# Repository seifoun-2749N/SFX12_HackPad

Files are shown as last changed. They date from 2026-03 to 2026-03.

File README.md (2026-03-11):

# SFX12 HackPad

<div align="center">

Affiche HackPad(1)

**A custom 12-key macropad with rotary encoder and SK6812 RGB LEDs.**

</div>

---

## Overview :

A custom macropad made with 12 mechanical switches and a rotay encoder with creative and chic design . It's also an open source device that you can build it yourself and costumize it like you want. 

---

## Features :

- 12 mechanical switches
- Rotary encoder
- 5 * SK6812 RGB LEDs 
- Tap dance on every key
- 12 app launchers
- Dedicated shortcut row

---

## Hardware :

* Seeeduino XIAO (1) SAMD21G18
* mechanical switches (12) MX-compatible
* EC11 (1) Rotary encoder with push button
* SK6812 (5) addressable RGB LEDs
* 1N4148 (12) signal diodes

---

## PCB and Shematics :

### PCB Front
PCB

### PCB Back
PCB Back

### Schematic


---

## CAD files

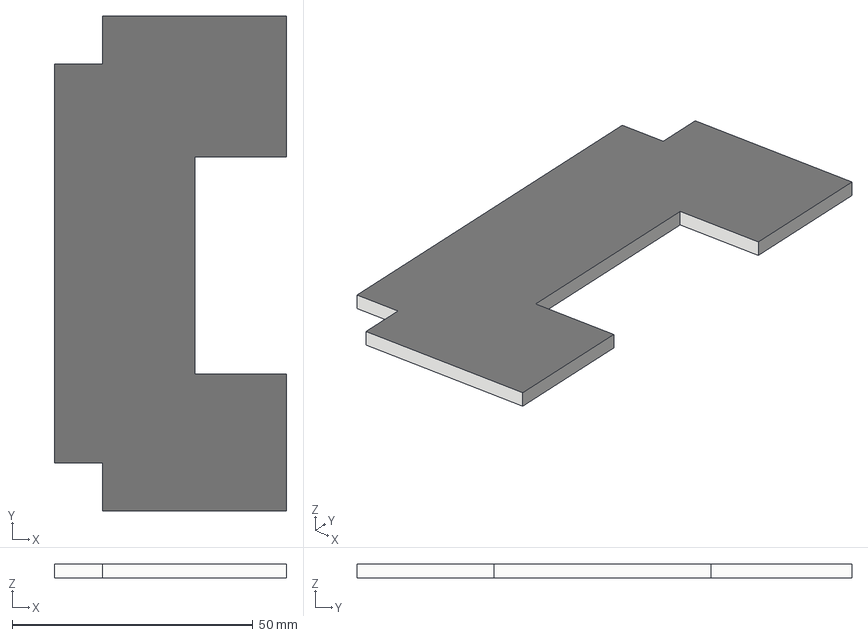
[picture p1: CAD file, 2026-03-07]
Cad/Transparent Layer.step
48.3 x 102.9 x 3.00 mm

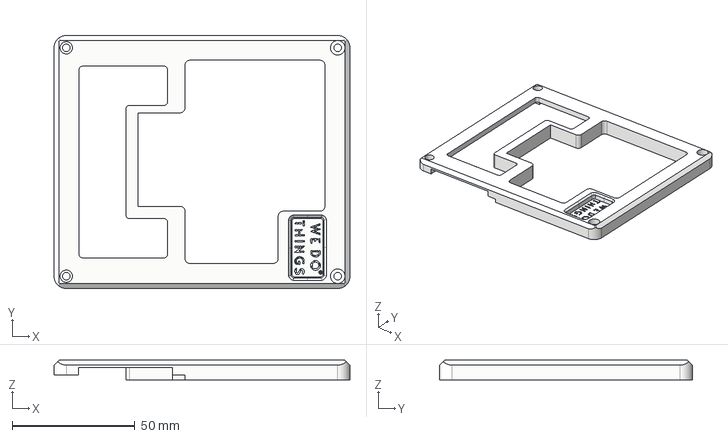
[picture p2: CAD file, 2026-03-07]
Cad/Top.step
120.4 x 102.9 x 8.00 mm

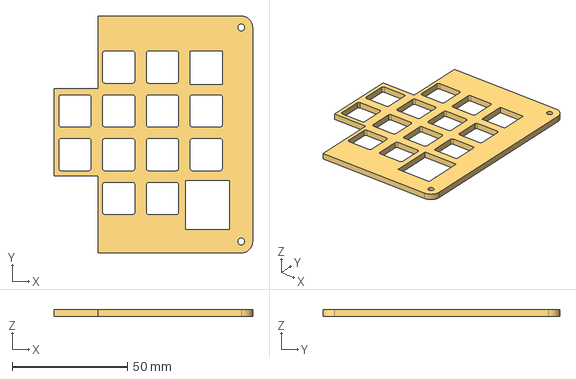
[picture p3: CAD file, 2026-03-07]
Cad/Frame.step
86.2 x 102.9 x 3.00 mm

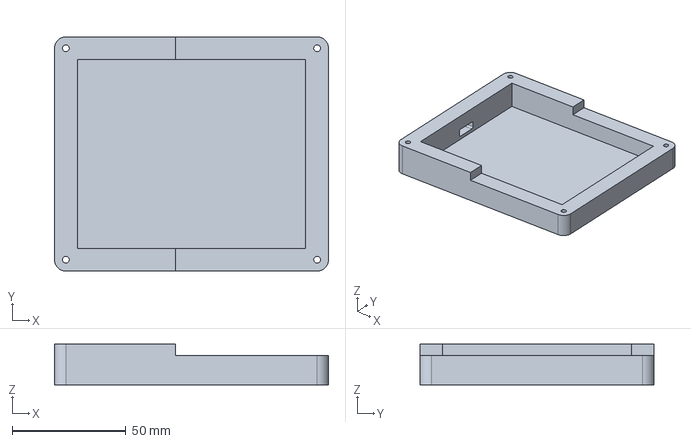
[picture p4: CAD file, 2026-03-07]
Cad/Base.step
120.4 x 102.9 x 18.0 mm

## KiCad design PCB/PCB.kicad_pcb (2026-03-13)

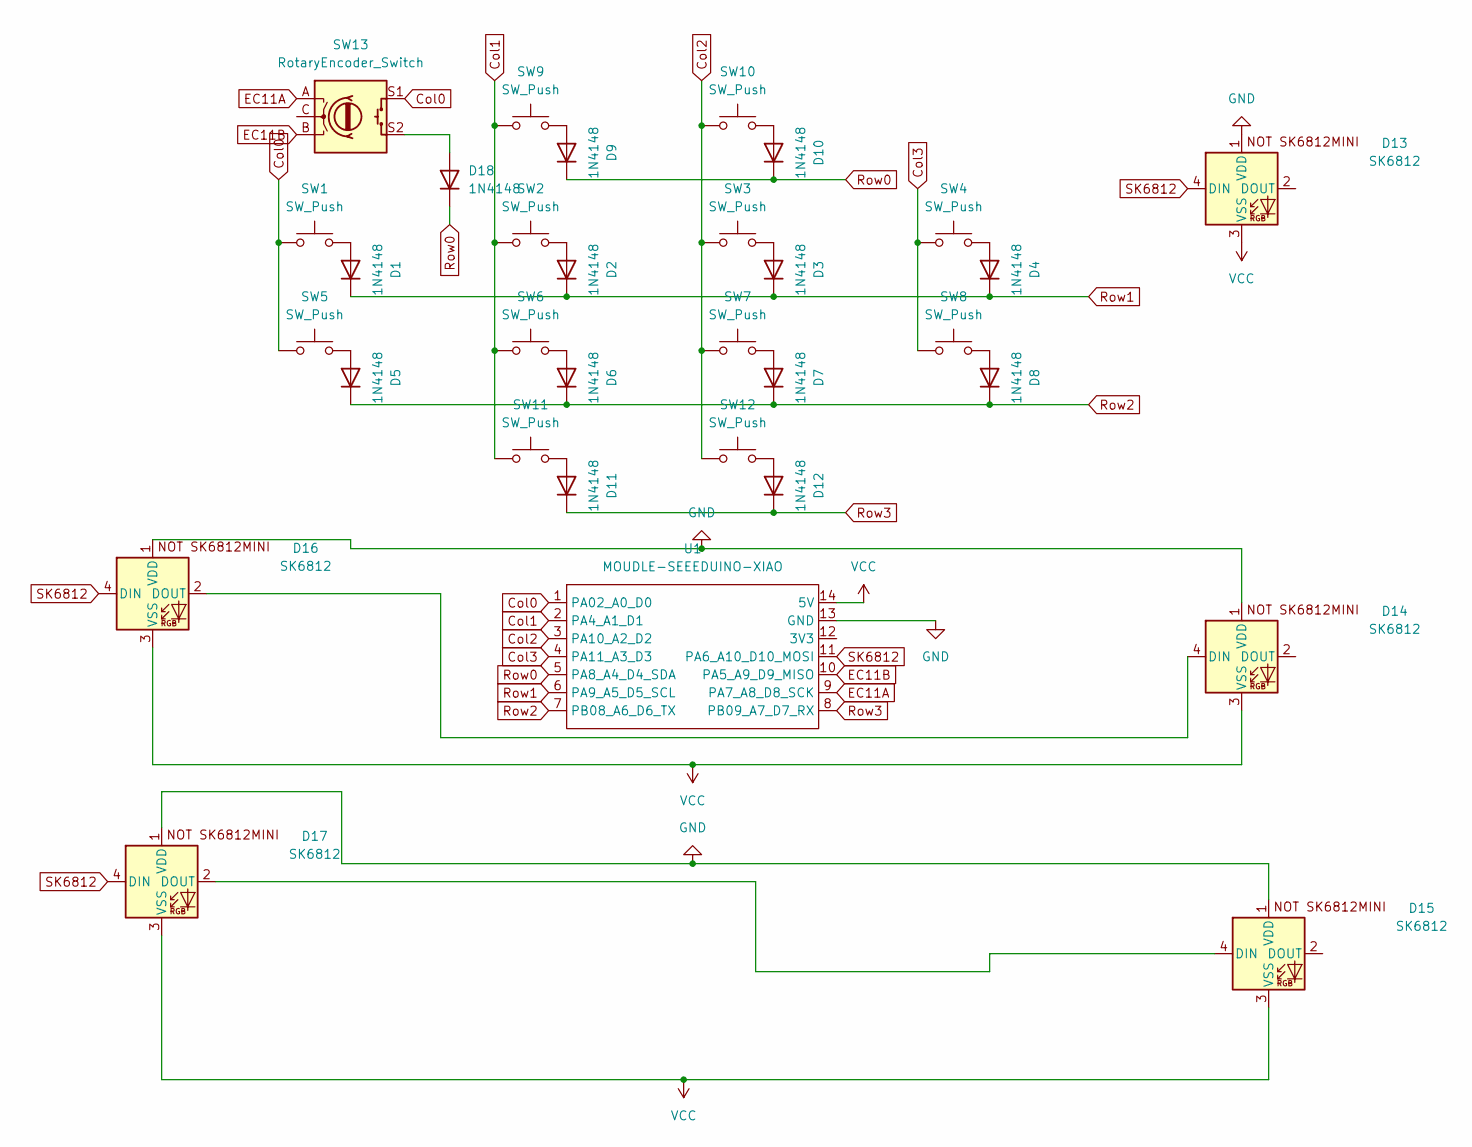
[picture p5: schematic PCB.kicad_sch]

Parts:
D1, D2, D3, D4, D5, D6, D7, D8, D9, D10, D11, D12, D18: 1N4148; D_DO-35_SOD27_P7.62mm_Horizontal
D13, D14, D15, D16, D17: SK6812; SK6812MINI-E - 3.2x2.8x1.78mm
SW1, SW2, SW3, SW4, SW5, SW6, SW7, SW8, SW9, SW10, SW11, SW12: SW_Push; SW_Cherry_MX_1.00u_PCB
SW13: RotaryEncoder_Switch; RotaryEncoder_Alps_EC11E-Switch_Vertical_H20mm
U1: MOUDLE-SEEEDUINO-XIAO; XIAO-Generic-Hybrid-14P-2.54-21X17.8MM

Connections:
Col0: SW1.1, SW5.1, SW13.S1, U1.1 (PA02_A0_D0)
Col1: SW2.1, SW6.1, SW9.1, SW11.1, U1.2 (PA4_A1_D1)
Col2: SW3.1, SW7.1, SW10.1, SW12.1, U1.3 (PA10_A2_D2)
Col3: SW4.1, SW8.1, U1.4 (PA11_A3_D3)
EC11A: SW13.A, U1.9 (PA7_A8_D8_SCK)
EC11B: SW13.B, U1.10 (PA5_A9_D9_MISO)
GND: D13.1 (VDD), D14.1 (VDD), D15.1 (VDD), D16.1 (VDD), D17.1 (VDD), U1.13 (GND)
unnamed: D1.2 (A), SW1.2
unnamed: D2.2 (A), SW2.2
unnamed: D3.2 (A), SW3.2
unnamed: D4.2 (A), SW4.2
unnamed: D5.2 (A), SW5.2
unnamed: D6.2 (A), SW6.2
unnamed: D7.2 (A), SW7.2
unnamed: D8.2 (A), SW8.2
unnamed: D9.2 (A), SW9.2
unnamed: D10.2 (A), SW10.2
unnamed: D11.2 (A), SW11.2
unnamed: D12.2 (A), SW12.2
unnamed: D14.4 (DIN), D16.2 (DOUT)
unnamed: D15.4 (DIN), D17.2 (DOUT)
unnamed: D18.2 (A), SW13.S2
Row0: D9.1 (K), D10.1 (K), D18.1 (K), U1.5 (PA8_A4_D4_SDA)
Row1: D1.1 (K), D2.1 (K), D3.1 (K), D4.1 (K), U1.6 (PA9_A5_D5_SCL)
Row2: D5.1 (K), D6.1 (K), D7.1 (K), D8.1 (K), U1.7 (PB08_A6_D6_TX)
Row3: D11.1 (K), D12.1 (K), U1.8 (PB09_A7_D7_RX)
SK6812: D13.4 (DIN), D16.4 (DIN), D17.4 (DIN), U1.11 (PA6_A10_D10_MOSI)
VCC: D13.3 (VSS), D14.3 (VSS), D15.3 (VSS), D16.3 (VSS), D17.3 (VSS), U1.14 (5V)

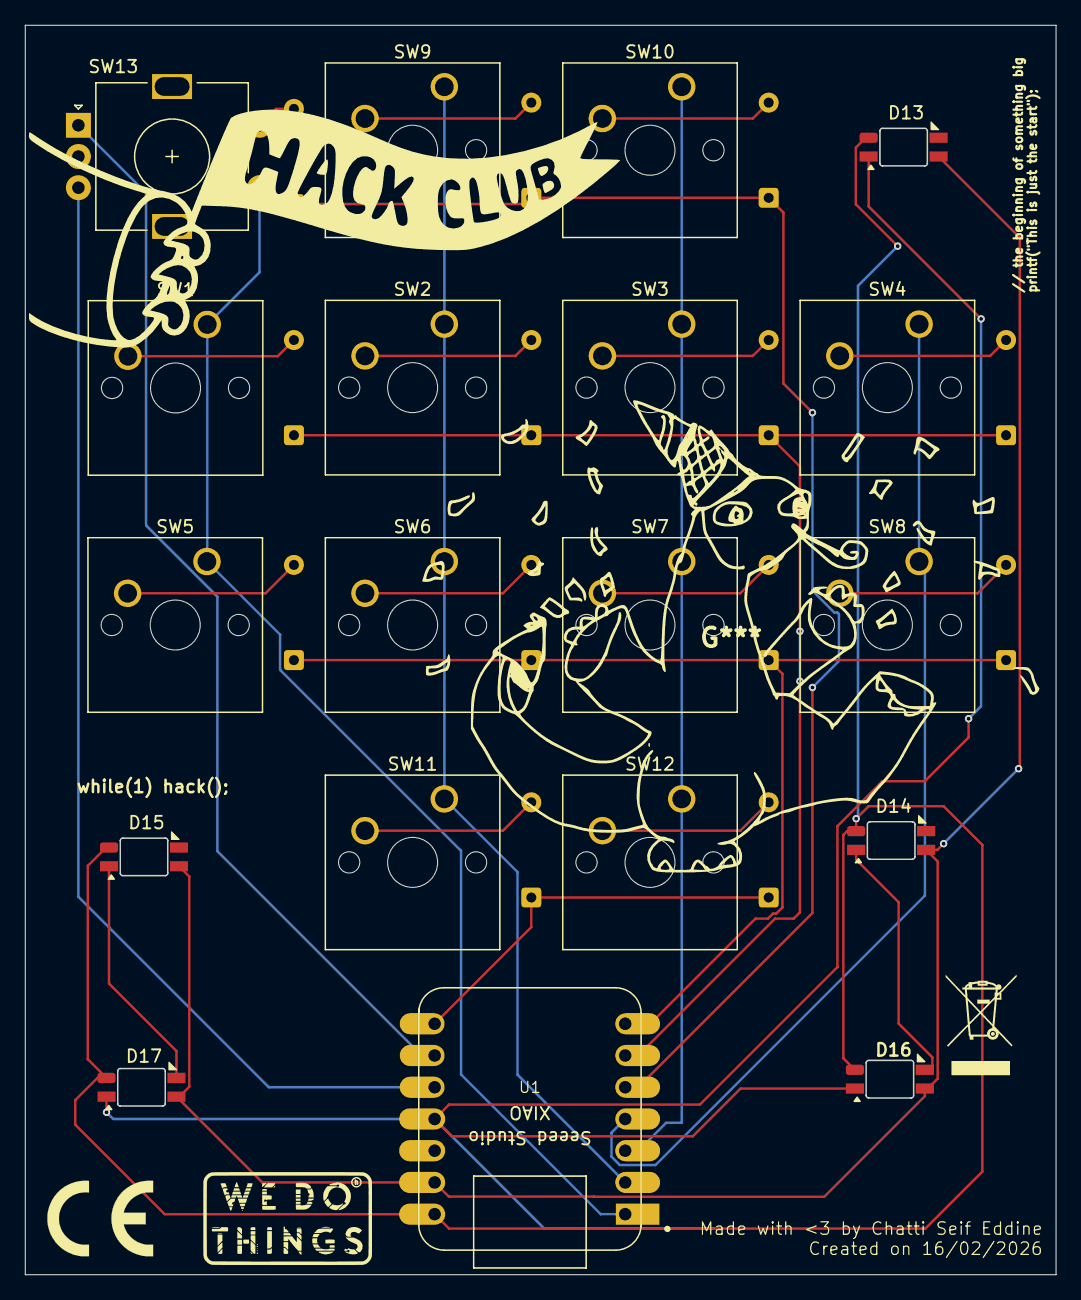
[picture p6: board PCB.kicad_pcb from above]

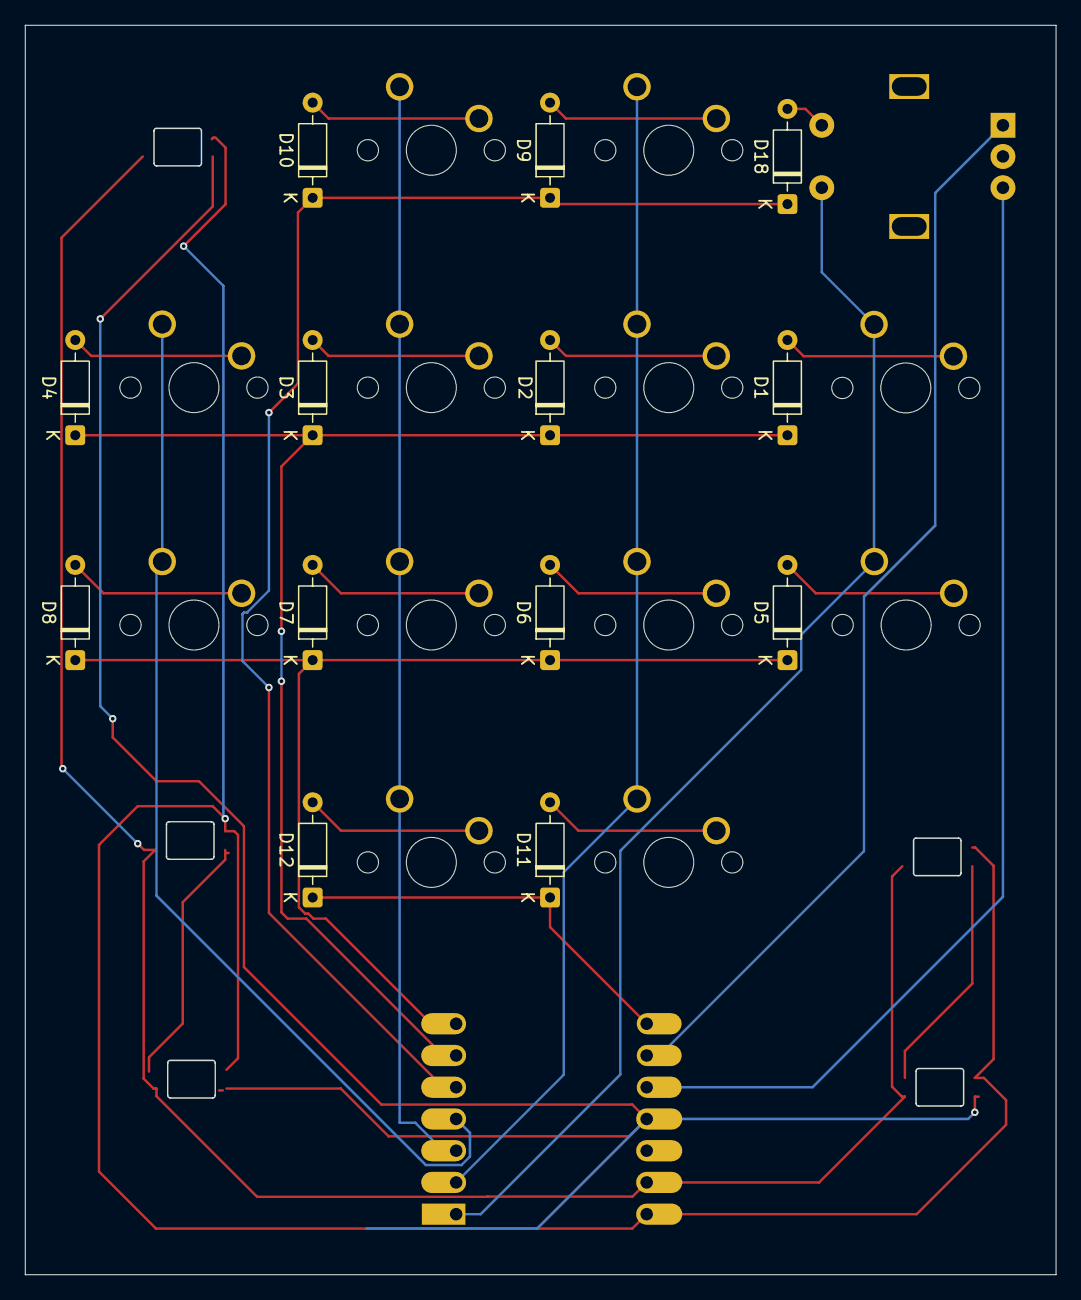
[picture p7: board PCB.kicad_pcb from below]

Board: 2 copper layers, 82.5 x 100.0 mm, 32 parts (13 on the bottom side), 28 nets.

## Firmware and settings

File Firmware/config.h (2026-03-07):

#pragma once

// RGB LEDs — SK6812 (RGBW)
#define RGBLED_NUM 6
#define RGB_DI_PIN B9
#define RGBLIGHT_DRIVER SK6812
#define SK6812_RGBW      
#define RGBLIGHT_EFFECT_BREATHING
#define RGBLIGHT_EFFECT_RAINBOW_MOOD
#define RGBLIGHT_EFFECT_RAINBOW_SWIRL
#define RGBLIGHT_EFFECT_SNAKE
#define RGBLIGHT_EFFECT_KNIGHT
#define RGBLIGHT_HUE_STEP 8
#define RGBLIGHT_SAT_STEP 8
#define RGBLIGHT_VAL_STEP 8

// Encoder
#define ENCODER_RESOLUTION 4

// Tap Dance
#define TAPPING_TERM 200

// Debounce
#define DEBOUNCE 5

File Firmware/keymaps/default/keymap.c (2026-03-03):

#include QMK_KEYBOARD_H

// ============================================================
//  SFX12 HACKPAD — KEYMAP (ROW-BASED ASSIGNMENT)
// ============================================================
//
//  PHYSICAL LAYOUT
//
//  [ ENC  ]              [ K01    ]  [ K02    ]     ← ROW 0: Apps
//           [ K03    ]  [ K04    ]  [ K05    ]  [ K06    ]  ← ROW 1: Apps
//           [ K07    ]  [ K08    ]  [ K09    ]  [ K10    ]  ← ROW 2: Shortcuts
//                       [ K11    ]  [ K12    ]              ← ROW 3: RGB
//
//  ROW 0 (ENC, K01, K02) → App launchers
//  ROW 1 (K03–K06)       → App launchers
//  ROW 2 (K07–K10)       → PC Shortcuts
//  ROW 3 (K11, K12)      → RGB Control
//
//  ENCODER: CCW = Vol Down | CW = Vol Up | Button = N/A
//
// ── APP ASSIGNMENTS (by priority rank) ──────────────────────
//
//  K01: Photoshop      / Premiere Pro    (1st, 3rd)
//  K02: Discord        / After Effects   (2nd, 5th)
//  K03: Fusion 360     / VS Code         (4th, 6th)
//  K04: KiCad          / Arduino IDE     (7th, 8th)
//  K05: YouTube Music  / WhatsApp        (9th, 10th)
//  K06: Illustrator    / Streamlabs      (11th, 12th)
//
// ── SHORTCUT ASSIGNMENTS ────────────────────────────────────
//
//  K07: Task Manager   / Settings (Win+I)
//  K08: GPU Refresh    / Audio Output Switch
//  K09: Mic Mute       / Screenshot (Win+Shift+S)
//  K10: Lock PC        / Show Desktop
//
// ── RGB ─────────────────────────────────────────────────────
//
//  K11: RGB Toggle
//  K12: RGB Mode cycle
//
// ============================================================

// ── Tap Dance IDs ───────────────────────────────────────────
enum tap_dance_keys {
    // Row 0 + Row 1 — Apps
    TD_PS_PR,      // K01: Photoshop / Premiere Pro
    TD_DC_AE,      // K02: Discord / After Effects
    TD_F360_VSC,   // K03: Fusion 360 / VS Code
    TD_KCD_ARD,    // K04: KiCad / Arduino IDE
    TD_YTM_WA,     // K05: YouTube Music / WhatsApp
    TD_AI_SL,      // K06: Illustrator / Streamlabs

    // Row 2 — Shortcuts
    TD_TSK_SET,    // K07: Task Manager / Settings
    TD_GPU_AU,     // K08: GPU Refresh / Audio Switch
    TD_MUTE_SS,    // K09: Mic Mute / Screenshot
    TD_LOCK_DSK,   // K10: Lock PC / Show Desktop
};

// ── App launch helpers ──────────────────────────────────────

// Win+R → run command (for apps registered in PATH)
static void launch_run(const char *cmd) {
    register_code(KC_LGUI);
    tap_code(KC_R);
    unregister_code(KC_LGUI);
    wait_ms(400);
    send_string(cmd);
    tap_code(KC_ENT);
}

// Win key → search (for apps without a run command)
static void launch_search(const char *name) {
    tap_code(KC_LGUI);
    wait_ms(500);
    send_string(name);
    wait_ms(600);
    tap_code(KC_ENT);
}

// Run a PowerShell script saved in the user profile folder
static void run_ps_script(const char *script) {
    register_code(KC_LGUI);
    tap_code(KC_R);
    unregister_code(KC_LGUI);
    wait_ms(400);
    send_string("powershell -ExecutionPolicy Bypass -File \"%USERPROFILE%\\");
    send_string(script);
    send_string("\"");
    tap_code(KC_ENT);
}

// ── Tap Dance callbacks ─────────────────────────────────────

// K01 — Photoshop (1tap) / Premiere Pro (2tap)
void td_ps_pr_fn(tap_dance_state_t *state, void *user_data) {
    if (state->count == 1)      launch_run("photoshop");
    else if (state->count == 2) launch_run("Adobe Premiere Pro");
}

// K02 — Discord (1tap) / After Effects (2tap)
void td_dc_ae_fn(tap_dance_state_t *state, void *user_data) {
    if (state->count == 1)      launch_run("discord");
    else if (state->count == 2) launch_run("afterfx");
}

// K03 — Fusion 360 (1tap) / VS Code (2tap)
void td_f360_vsc_fn(tap_dance_state_t *state, void *user_data) {
    if (state->count == 1)      launch_search("Fusion 360");
    else if (state->count == 2) launch_run("code");
}

// K04 — KiCad (1tap) / Arduino IDE (2tap)
void td_kcd_ard_fn(tap_dance_state_t *state, void *user_data) {
    if (state->count == 1)      launch_search("KiCad");
    else if (state->count == 2) launch_search("Arduino IDE");
}

// K05 — YouTube Music (1tap) / WhatsApp (2tap)
void td_ytm_wa_fn(tap_dance_state_t *state, void *user_data) {
    if (state->count == 1)      launch_run("https://music.youtube.com");
    else if (state->count == 2) launch_search("WhatsApp");
}

// K06 — Illustrator (1tap) / Streamlabs (2tap)
void td_ai_sl_fn(tap_dance_state_t *state, void *user_data) {
    if (state->count == 1)      launch_run("illustrator");
    else if (state->count == 2) launch_search("Streamlabs");
}

// K07 — Task Manager (1tap) / Settings (2tap)
void td_tsk_set_fn(tap_dance_state_t *state, void *user_data) {
    if (state->count == 1) {
        // Ctrl+Shift+Esc
        register_code(KC_LCTL);
        register_code(KC_LSFT);
        tap_code(KC_ESC);
        unregister_code(KC_LSFT);
        unregister_code(KC_LCTL);
    } else if (state->count == 2) {
        // Win+I
        register_code(KC_LGUI);
        tap_code(KC_I);
        unregister_code(KC_LGUI);
    }
}

// K08 — GPU Refresh (1tap) / Audio Output Switch (2tap)
void td_gpu_au_fn(tap_dance_state_t *state, void *user_data) {
    if (state->count == 1) {
        // Alt+Ctrl+Shift+B
        register_code(KC_LALT);
        register_code(KC_LCTL);
        register_code(KC_LSFT);
        tap_code(KC_B);
        unregister_code(KC_LSFT);
        unregister_code(KC_LCTL);
        unregister_code(KC_LALT);
    } else if (state->count == 2) {
        // Runs switch_audio.ps1 — see README for setup
        run_ps_script("switch_audio.ps1");
    }
}

// K09 — Mic Mute (1tap) / Screenshot Win+Shift+S (2tap)
void td_mute_ss_fn(tap_dance_state_t *state, void *user_data) {
    if (state->count == 1) {
        tap_code(KC_MUTE);
    } else if (state->count == 2) {
        // Win+Shift+S = Snipping Tool
        register_code(KC_LGUI);
        register_code(KC_LSFT);
        tap_code(KC_S);
        unregister_code(KC_LSFT);
        unregister_code(KC_LGUI);
    }
}

// K10 — Lock PC (1tap) / Show Desktop (2tap)
void td_lock_dsk_fn(tap_dance_state_t *state, void *user_data) {
    if (state->count == 1) {
        // Win+L
        register_code(KC_LGUI);
        tap_code(KC_L);
        unregister_code(KC_LGUI);
    } else if (state->count == 2) {
        // Win+D
        register_code(KC_LGUI);
        tap_code(KC_D);
        unregister_code(KC_LGUI);
    }
}
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
